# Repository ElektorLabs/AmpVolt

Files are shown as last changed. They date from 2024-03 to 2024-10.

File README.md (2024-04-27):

# AmpVolt: VI Measurement Module - 240141 📊

## Overview 🌐
AmpVolt, designed for the any Arduino or ESP32 project, is a  module for accurately measuring current and voltage with ease. Featuring a voltage divider, INA169 for current sensing, and an ADS1015 ADC, it's equipped with an OLED display for immediate feedback. Suitable for electrical projects requiring up to 50V and 5A measurements, it offers modular connectivity through Grove, Qwiic, and 2.54mm pitch connectors.

## Key Features 🚀
- Precise current and voltage measurement up to 50V and 5A.
- Modular design with Grove, Qwiic, and standard connectors.
- Real-time data display on an OLED screen.
- Tested on ESP32-C3 Mini.

## Hardware Design 🛠️
AmpVolt's PCB is designed for flexibility, featuring various connectors to suit diverse project needs. The inclusion of Grove and Qwiic connectors alongside traditional 2.54mm pitch options ensures compatibility with a wide range of devices and systems.

## Function Descriptions 📖

### `setup()`
Initializes the system: sets up serial communication, I2C parameters, ADC gain, and data rate for quick measurements, and checks the OLED display's status.

### `loop()`
Main program loop: periodically reads commands, updates measurements, calculates energy consumed, and refreshes the OLED display with current data.

### `readVoltage()`
Reads and calculates the voltage from ADS1115 based on the voltage divider's configuration. It applies corrections for zero error and scales the reading according to the resistive divider ratio.

### `readCurrent()`
Measures the current using the INA169 and ADS1115, adjusting the value with a calibration factor to account for zero error and component variations.

### `calculateAndSendAdditionalData()`
Compiles voltage, current, and calculated power into a comprehensive dataset, including energy consumed and battery state of charge (SoC), then outputs this information through the serial port in JSON format.

### `readCommand()`
Listens for incoming serial commands, assembling them character-by-character until a newline character is encountered, indicating a complete command ready for processing.

### `sendData(String type)`
Responds to specific command types by reading sensor values, performing calculations, and sending the requested data back through the serial port.

### `updateDisplay()`
Refreshes the OLED display with the latest measurement data, including voltage, current, power, elapsed time, battery capacity, energy consumed, and remaining battery percentage.

## Installation & Usage 💡
Follow detailed steps to clone the repo, prepare your microcontroller, assemble the module, and start measuring with the provided Arduino sketch.

## Acknowledgements 🙏
Credits to the creators of the ADS1X15 and Adafruit libraries, enabling the AmpVolt project to utilize advanced ADC and display functionalities.

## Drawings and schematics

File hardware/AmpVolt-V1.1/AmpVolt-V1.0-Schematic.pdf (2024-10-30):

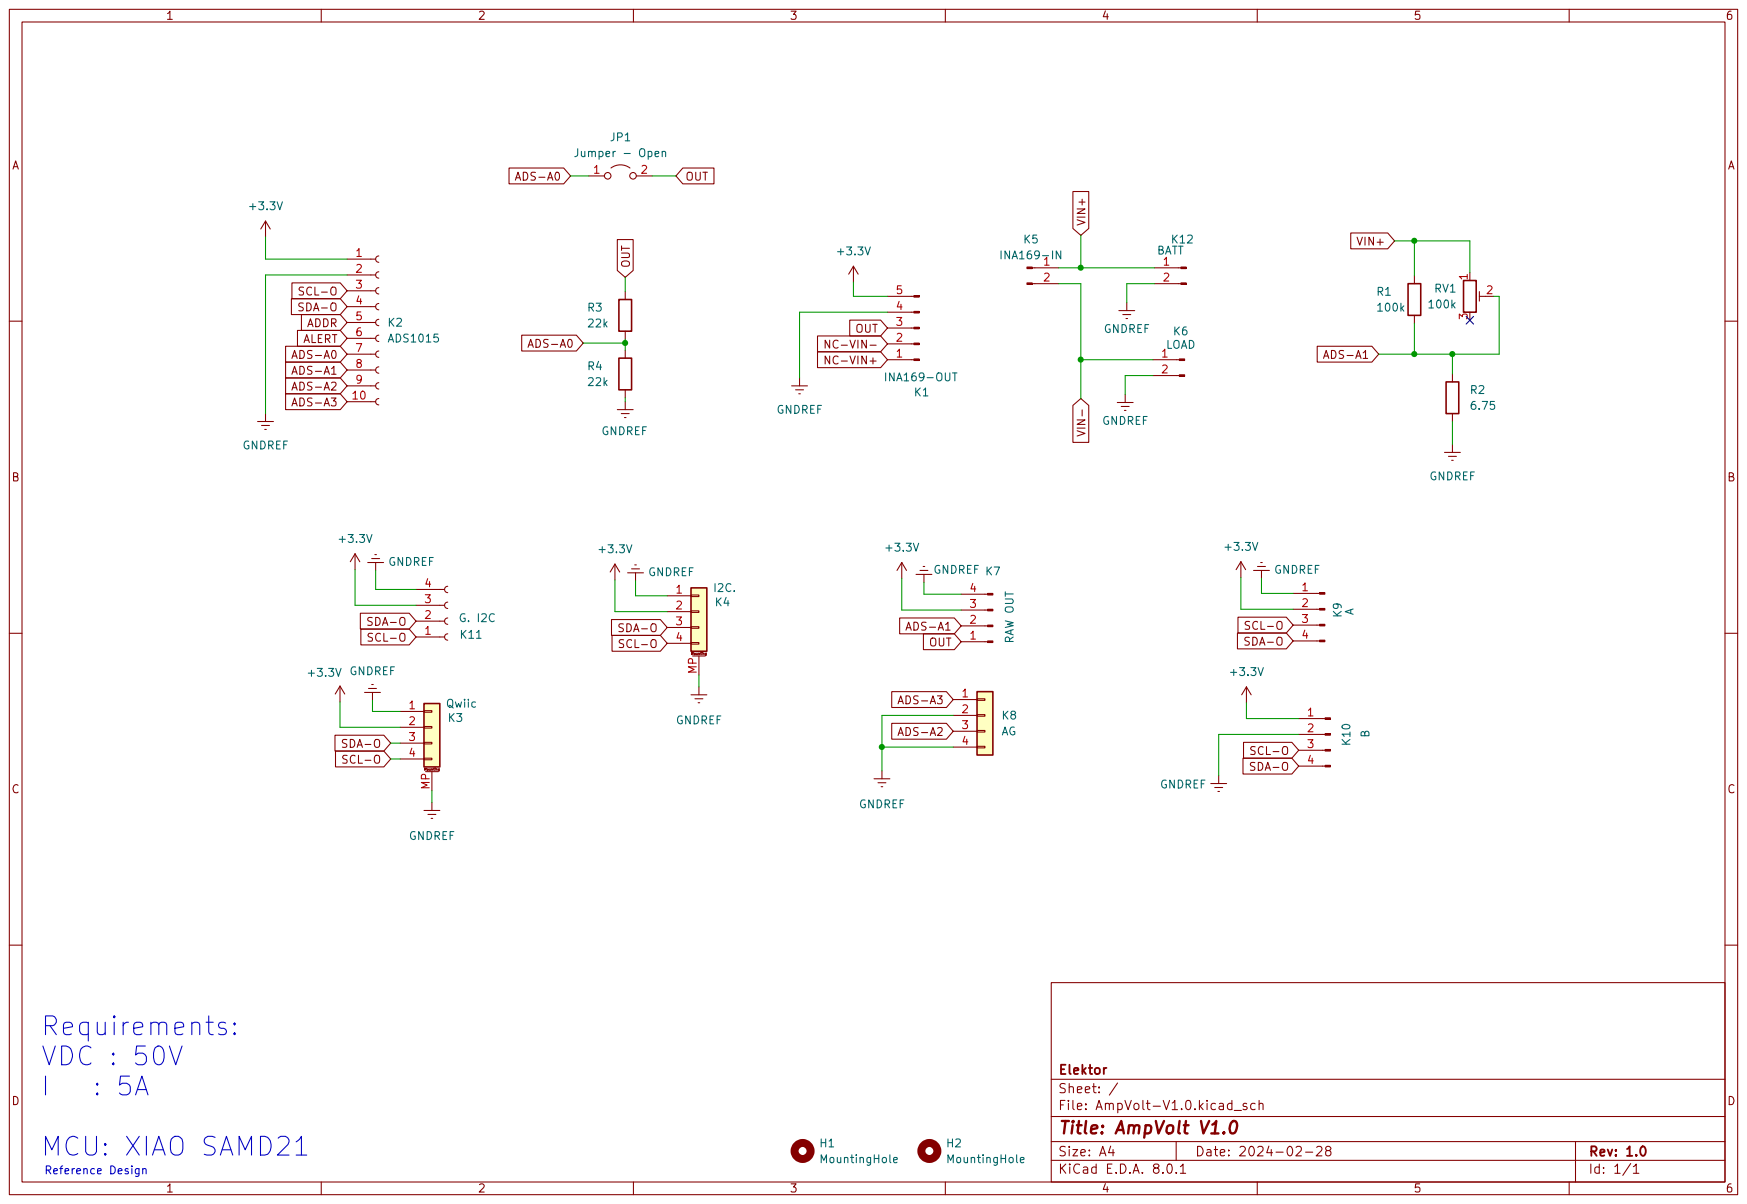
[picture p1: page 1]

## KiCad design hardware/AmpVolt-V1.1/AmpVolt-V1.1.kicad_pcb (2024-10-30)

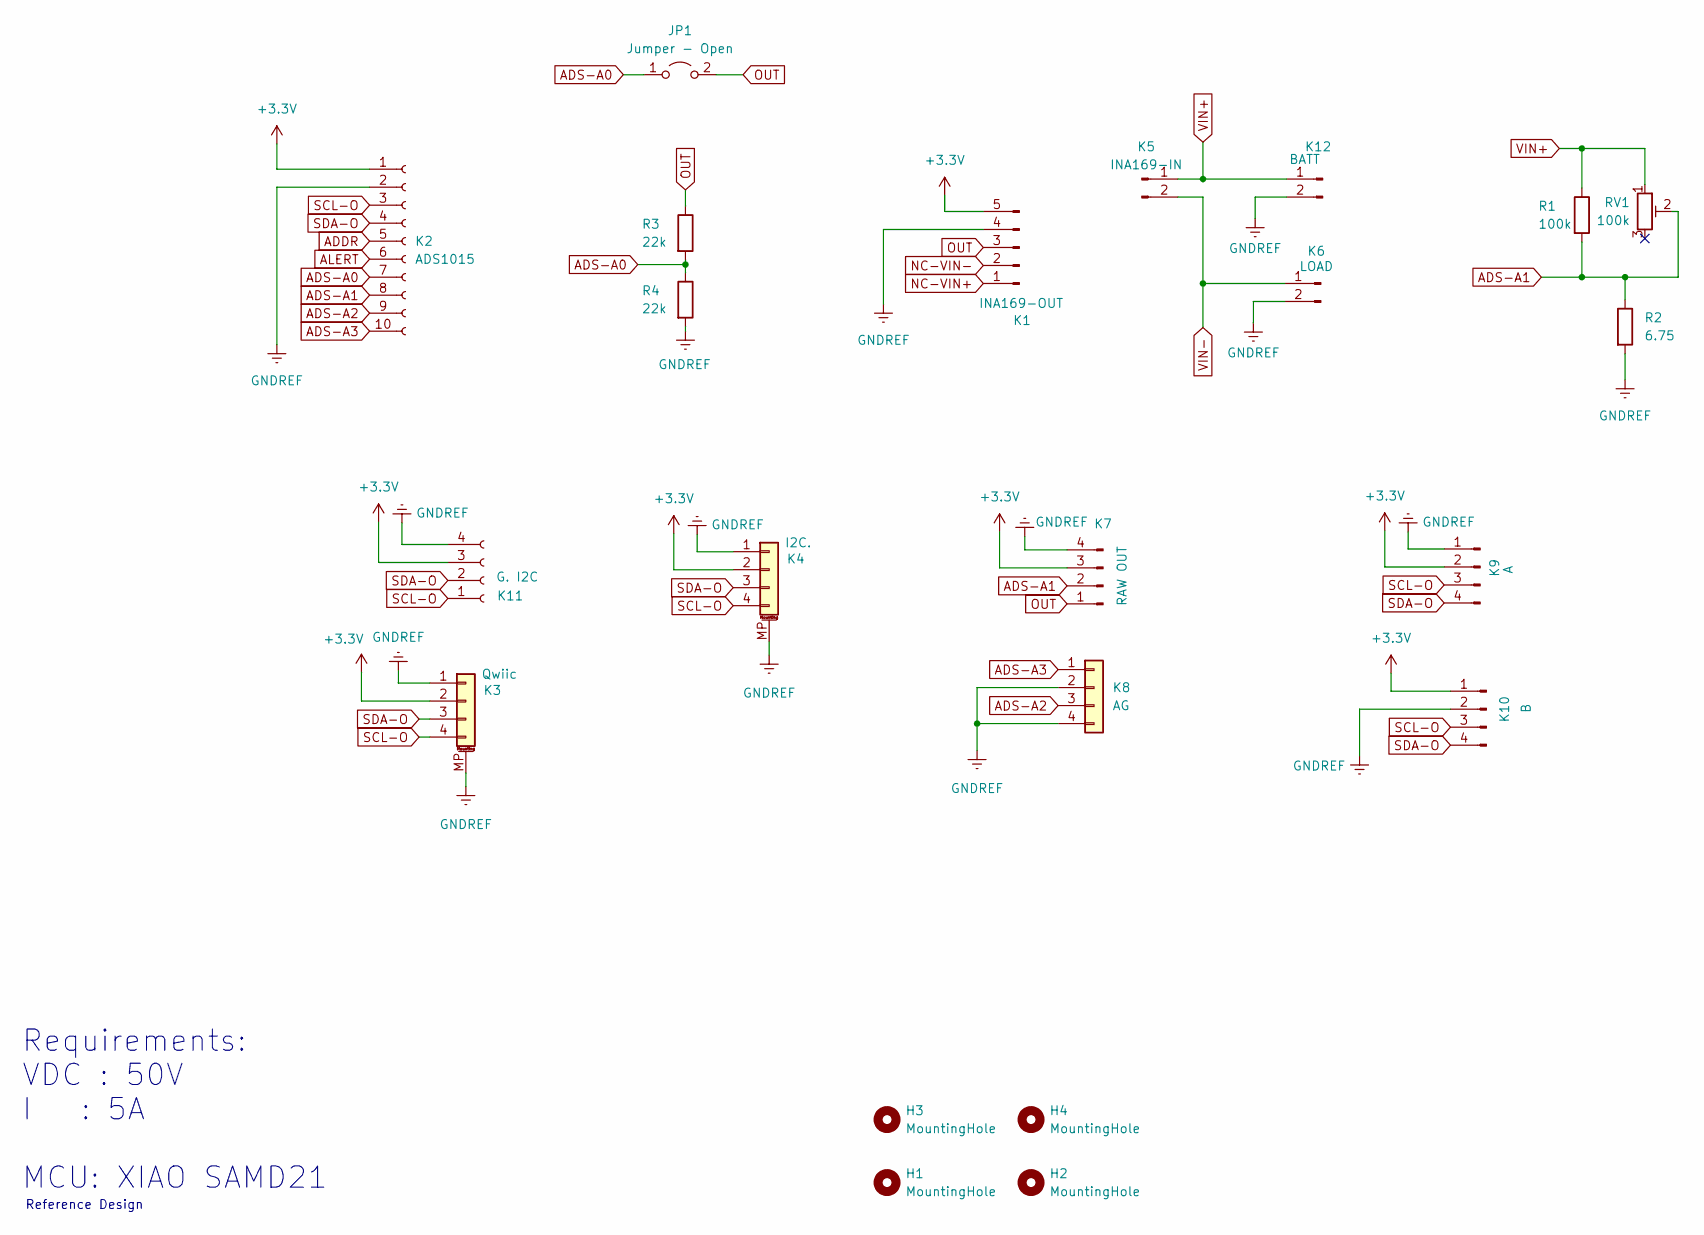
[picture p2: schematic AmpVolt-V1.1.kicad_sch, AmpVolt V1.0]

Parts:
H1, H2, H3, H4: MountingHole; MountingHole_3.2mm_M3_DIN965_Pad_TopOnly
JP1: Jumper - Open; SolderJumper-2_P1.3mm_Open_TrianglePad1.0x1.5mm
K1: INA169-OUT; PinSocket_1x05_P2.54mm_Vertical
K2: ADS1015; PinHeader_1x10_P2.54mm_Vertical
K3: Qwiic; JST_SH_SM04B-SRSS-TB_1x04-1MP_P1.00mm_Horizontal
K4: I2C.; JST_PH_S4B-PH-SM4-TB_1x04-1MP_P2.00mm_Horizontal
K5: INA169-IN; PhoenixContact_MCV_1,5_2-G-5.08_1x02_P5.08mm_Vertical
K6: LOAD; AMASS_XT60PW-F_1x02_P7.20mm_Horizontal
K7: RAW OUT; PinHeader_1x04_P2.54mm_Vertical
K8: AG; PinHeader_1x04_P2.54mm_Vertical
K9: A; PinHeader_1x04_P2.54mm_Vertical
K10: B; PinHeader_1x04_P2.54mm_Vertical
K11: G. I2C; JST_EH_S4B-EH_1x04_P2.50mm_Horizontal
K12: BATT; AMASS_XT60PW-F_1x02_P7.20mm_Horizontal
R1: 100k; R_Axial_DIN0204_L3.6mm_D1.6mm_P7.62mm_Horizontal
R2: 6.75; R_Axial_DIN0204_L3.6mm_D1.6mm_P7.62mm_Horizontal
R3, R4: 22k; R_Axial_DIN0204_L3.6mm_D1.6mm_P7.62mm_Horizontal
RV1: 100k; Potentiometer_Bourns_3296W_Vertical

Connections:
+3.3V: K1.5, K2.1, K3.2, K4.2, K7.3, K9.2, K10.1, K11.3
ADDR: K2.5
ADS-A0: JP1.1 (A), K2.7, R3.2, R4.1
ADS-A1: K2.8, K7.2, R1.2, R2.1, RV1.2
ADS-A2: K2.9, K8.3
ADS-A3: K2.10, K8.1
ALERT: K2.6
GNDREF: K1.4, K2.2, K3.1, K3.MP (MountPin), K4.1, K4.MP (MountPin), K6.2, K7.4, K8.2, K8.4, K9.1, K10.2, K11.4, K12.2, R2.2, R4.2
NC-VIN+: K1.1
NC-VIN-: K1.2
OUT: JP1.2 (B), K1.3, K7.1, R3.1
SCL-O: K2.3, K3.4, K4.4, K9.3, K10.3, K11.1
SDA-O: K2.4, K3.3, K4.3, K9.4, K10.4, K11.2
VIN+: K5.1, K12.1, R1.1, RV1.1
VIN-: K5.2, K6.1

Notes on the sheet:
Requirements: VDC : 50V I : 5A MCU: XIAO SAMD21
Reference Design

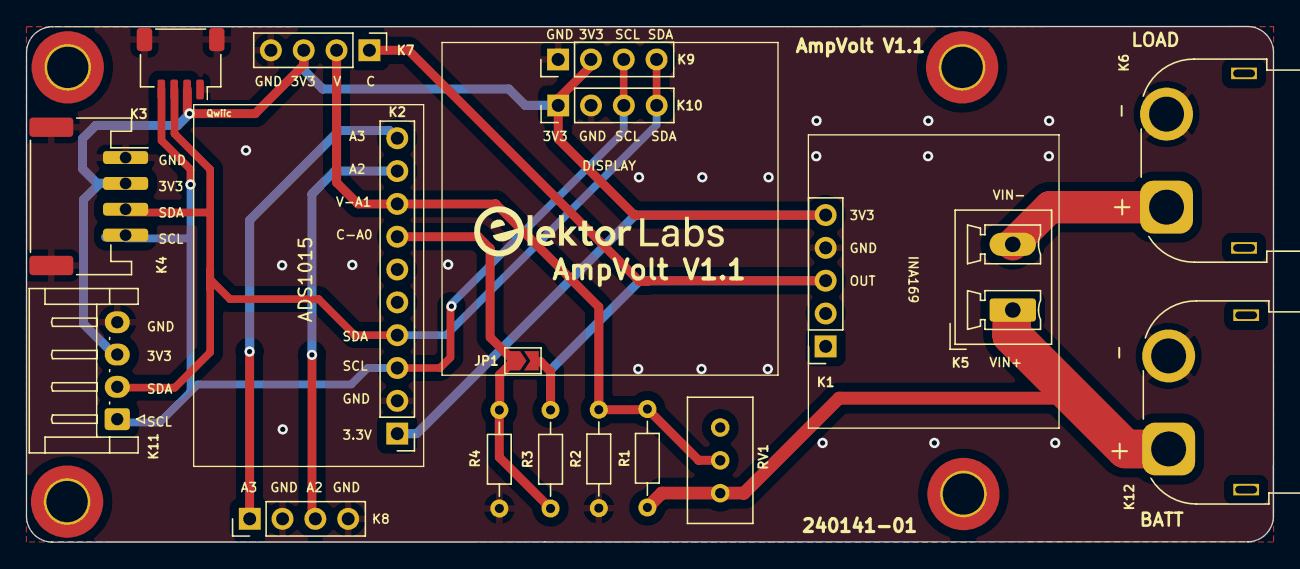
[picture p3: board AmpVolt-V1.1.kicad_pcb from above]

Board: 2 copper layers, 96.5 x 39.9 mm, 22 parts (0 on the bottom side), 11 nets.

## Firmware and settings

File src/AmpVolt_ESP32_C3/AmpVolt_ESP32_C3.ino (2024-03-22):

/*
  ADS1X15 Libaray :  https://github.com/RobTillaart/ADS1X15
*/


#include "ADS1X15.h"
#include "Arduino.h"
#include "driver/i2c.h"
#include "esp_log.h"
#include "config.h"
#include <Wire.h>
 #include <SPI.h>
#include <Adafruit_GFX.h>
#include <Adafruit_SSD1306.h>


ADS1115 ADS(0x48);
Adafruit_SSD1306 display(SCREEN_WIDTH, SCREEN_HEIGHT, &Wire, OLED_RESET);


// Function Prototypes
float readVoltage();
float readCurrent();
void sendData(char type[2]);
void calculateAndSendAdditionalData();

// Global Variables for Energy Calculation
unsigned long previousMillis = 0; // Stores the last time the energy was updated
float energyConsumed = 0; // Total energy consumed over time in Watt-hours (Wh)
unsigned long startTime;


void setup() 
{
  Serial.begin(115200);
  startTime = millis(); // Save the start time
  Wire.setPins(I2C_SDA, I2C_SCL);
  Wire.begin(I2C_SDA, I2C_SCL);
  Wire.setClock(100000);
  ADS.begin();
   // SSD1306_SWITCHCAPVCC = generate display voltage from 3.3V internally
  if(!display.begin(SSD1306_SWITCHCAPVCC, SCREEN_ADDRESS)) {
    Serial.println(F("SSD1306 allocation failed"));
    //for(;;); // Don't proceed, loop forever
}

  ADS.setGain(0);
  ADS.setDataRate(7); // Fast Date Rate Mode 
  
  display.display();
  delay(2000); 
  display.clearDisplay();
}

void loop() 
{ 
    String command = readCommand(); // Read a complete command from serial
  if (command != "") {
    sendData(command);
  }

  // Periodic energy update (example: every 1 second)
  unsigned long currentMillis = millis();
  if (currentMillis - previousMillis >= 1000) {
    previousMillis = currentMillis;
    float current = readCurrent(); // Read current in Amps
    float voltage = readVoltage(); // Read voltage in Volts
    float power = voltage * current; // Calculate power in Watts
    energyConsumed += power / 3600; // Convert power to Wh and accumulate
  }

  updateDisplay();
}


float readVoltage(){
  int16_t val_0 = ADS.readADC(1);  
  float f = ADS.toVoltage(1); 
  float voltage = fabs((val_0 *f) * ((R1+R2)/R2) + ZERO_ERROR_V);

  return voltage;
}

float readCurrent(){
    int16_t val_1 = ADS.readADC(0); 
    float f = ADS.toVoltage(1); 
    float current = (val_1 *f) * ((R3+R4)/R4) + ZERO_ERROR_C;

  return current;
}

void calculateAndSendAdditionalData() {
  float voltage = readVoltage();
  float current = readCurrent();
  float power = voltage * current; // Power in Watts


  // enter the batteryCapacityWh in config.h
  float soc = (energyConsumed / batteryCapacityWh) * 100; // State of Charge in percentage

  // Send all data in JSON format
  Serial.print("{");
  Serial.print("\"voltage\": "); Serial.print(voltage, 3);
  Serial.print(", \"current\": "); Serial.print(current, 3);
  Serial.print(", \"power\": "); Serial.print(power, 3);
  Serial.print(", \"energyConsumed\": "); Serial.print(energyConsumed, 3);
  Serial.print(", \"stateOfCharge\": "); Serial.print(soc, 3);
  Serial.println("}");
}


String readCommand() {
  static String command = ""; // Hold the incoming serial command
  while (Serial.available() > 0) {
    char receivedChar = Serial.read();
    if (receivedChar == '\n') {
      String completedCommand = command; // Copy the completed command
      command = ""; // Reset command buffer
      return completedCommand; // Return the completed command
    } else {
      command += receivedChar; // Add received character to the command string
    }
  }
  return ""; // Return an empty string if the command is not yet complete
}

void sendData(String type) {
  float voltage = readVoltage();
  float current = readCurrent();
  float power = voltage * current; // Calculating power
  
  if (type == "#i") { // Send current value
      Serial.println(current);
  } else if (type == "#v") { // Send voltage value
      Serial.println(voltage);
  } else if (type == "#p") { // send power 
      Serial.println(power);
  } else if (type == "#a") { // Send all values in JSON format
      calculateAndSendAdditionalData();
  }
}


void printValues(){
  Serial.print("V:");
  Serial.print(readVoltage());
  Serial.print(",");
  Serial.print("A:");
  Serial.println(readCurrent());
}

String elapsedTimeAsString() {
  unsigned long currentMillis = millis();
  unsigned long elapsedTime = currentMillis - startTime;

  int hours = (int)(elapsedTime / 3600000); // 3,600,000 milliseconds in an hour
  int mins = (int)((elapsedTime / 60000) % 60); // 60,000 milliseconds in a minute, % 60 to get remainder
  int secs = (int)((elapsedTime / 1000) % 60); // 1,000 milliseconds in a second, % 60 to get remainder

  char timeStr[9]; // Buffer to hold the time string, HH:MM:SS format requires 8 chars + 1 for null terminator
  sprintf(timeStr, "%02d:%02d:%02d", hours, mins, secs);

  return String(timeStr); // Convert char array to String and return
}

void updateDisplay(){
  display.clearDisplay();
  display.setTextSize(2);      // Normal 1:1 pixel scale
  display.setTextColor(SSD1306_WHITE); // Draw white text
  display.setCursor(5, 10);     // Start at top-left corner
  display.print(readVoltage());
  display.write("V");
  display.setCursor(5, 30);   
  display.print(readCurrent());
  display.write("A");
  float power = readCurrent() * readVoltage();
  display.setCursor(5, 50);   
  display.print(power);
  display.write("W");

  display.setTextSize(1);
  display.setCursor(80, 10);
  display.print(elapsedTimeAsString());

  display.setCursor(80, 20);
  display.print(batteryCapacityWh);
  display.write("Wh");

  display.setCursor(80, 30);
  display.print(energyConsumed);
  display.write("Wh");

  // enter the batteryCapacityWh in config.h
  float remainingBattery = 100 - ((energyConsumed / batteryCapacityWh) * 100) ; // State of Charge in percentage

  display.setCursor(80, 40);
  display.print(remainingBattery);
  display.write("%");

  display.display();
}

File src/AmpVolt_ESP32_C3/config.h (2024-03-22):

#define I2C_SDA 5
#define I2C_SCL 4

#define ZERO_ERROR_V 0
#define ZERO_ERROR_C 0.20

// Voltage Divider - Voltage 
#define R1 97.4
#define R2 6.75

// Voltage Divider - Current
#define R3 22000
#define R4 22000

// Assuming a fixed battery capacity for SoC estimation (e.g., 100Wh for demonstration)
#define batteryCapacityWh  40.4 // Replace with actual battery capacity

#define SCREEN_WIDTH 128 // OLED display width, in pixels
#define SCREEN_HEIGHT 64 // OLED display height, in pixels

#define OLED_RESET     -1 // Reset pin # (or -1 if sharing Arduino reset pin)
#define SCREEN_ADDRESS 0x3C ///< See datasheet for Address; 0x3D for 128x64, 0x3C
